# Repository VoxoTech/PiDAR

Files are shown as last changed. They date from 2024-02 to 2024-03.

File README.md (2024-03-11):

# PiDAR - DIY 360° 3D Panorama Scanner
## WORK IN PROGRESS!

### Core Features:
- **LiDAR**: custom serial driver for LDRobot **LD06**, **LD19** or **STL27L**
    - CRC package integrity check
    - calibrated PWM control using curve fitting
    - 2D live visualization and export (numpy or CSV)

- **Panorama**: 6K 360° spherical map
    - stitched from fisheye photos using [**Hugin** Panorama photo stitcher](https://hugin.sourceforge.io/)
    - constant camera exposure by reading EXIF data of automatic
    - constant white balance by iterative optimization of color gains

- **3D Scene**: assembly of 3D scenes from 2D planes based on angle and offsets
    - sampling **vertex colors from panorama**
    - Open3D visualization and export (PCD, PLY or [e57](https://github.com/davidcaron/pye57))
    - aligning multiple scenes using **global registration** and **ICP fine-tuning**
    - **Poisson Surface Meshing** (very slow on Pi4, recommended to run on PC)

### Hardware Specs:

- LDRobot LD06, LD19 or STL27L LiDAR
- Raspberry Pi HQ Camera with ArduCam M12 Lens [(M25156H18, p.7)](https://www.arducam.com/doc/Arducam_M12_Lens_Kit_for_Pi_HQ_Camera.pdf)
- Raspberry Pi 4
- NEMA17 42-23 stepper with A4988 driver

- Power Supply: 
    - v1: 2x _18650_ Batteries (7.2V) with step-down converter
    - v2: 10.000 mAh USB Powerbank with step-up converter

- 3D printed: 
    - custom housing with tripod mount ([v1 here](mechanical_design/v1))
    - M12 to C-Mount lens adapter ([thingiverse.com](https://www.thingiverse.com/thing:4444398))
    - NEMA17 planetary reduction gearbox ([printables.com](https://www.printables.com/de/model/782336-nema17-planetary-gearbox-fixed))

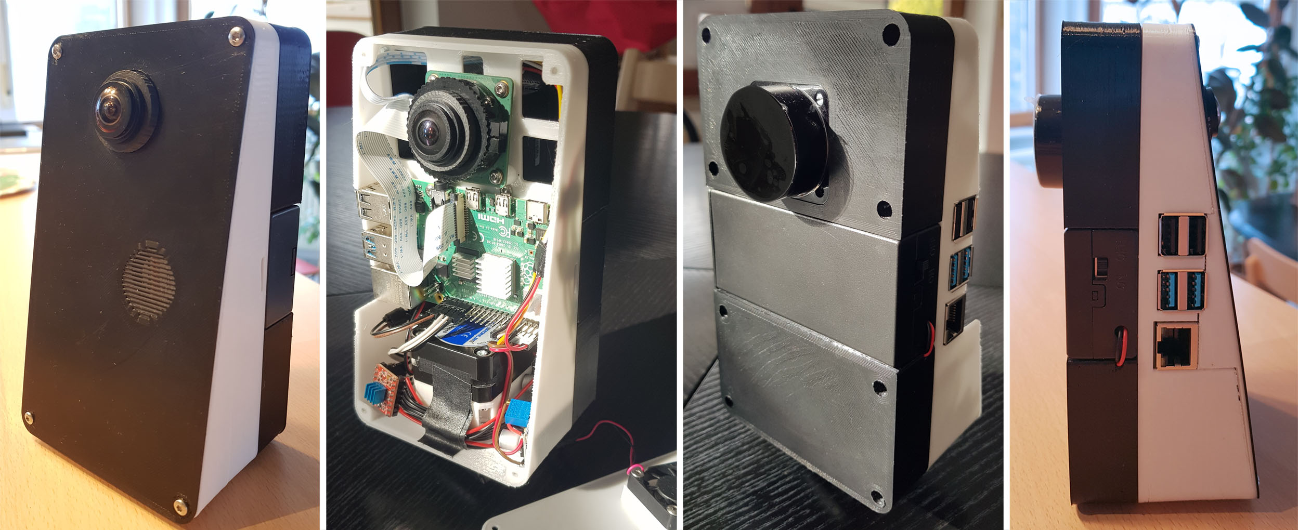
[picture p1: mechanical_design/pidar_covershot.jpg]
PiDAR 360° Laserscanner

Version 1 (using 2x 18650 Batteries):

## wiring

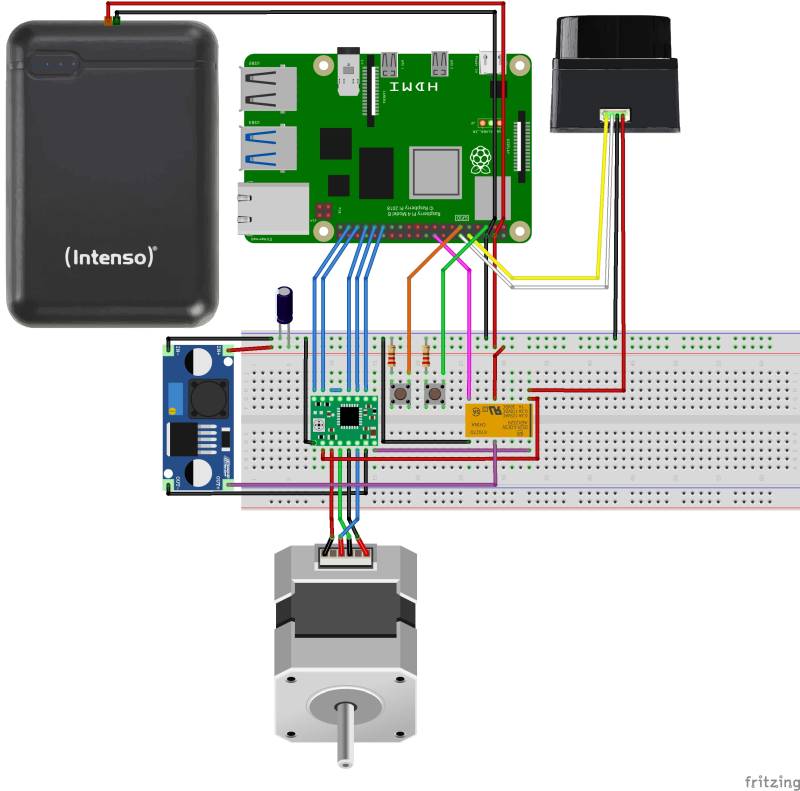
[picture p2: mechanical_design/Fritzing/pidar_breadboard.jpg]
breadboard version 2.0.1


Version 2 - (37Wh Powerbank with Step-Up converter + Relay for power efficiency)

### LD06 / STL27L:
- UART Tx (yellow)
- PWM (white)
- GND (black)
- VCC 5V (red)

### Raspberry Pi:
- LD06 UART0 Rx: GP15
- LD06 PWM0: GP18
- Power Button: GP03
- Scan Button: GP17
- A4988 direction: GP26, step: GP19
- A4988 microstepping mode: GP5, GP6, GP13

### Power Button 
- Wakeup is hardwired to Pin 3
- install [Shutdown script](https://github.com/Howchoo/pi-power-button)

### Power LED and CPU fan
    sudo nano /boot/firmware/config.txt

    # CPU fan at lower temp
    dtoverlay=gpio-fan,gpiopin=4,temp=45000

    # Power LED Heartbeat:
    dtparam=pwr_led_trigger=timer

### Scan Button: register GPIO interrupt

create new service for autostart

    sudo nano /etc/systemd/system/pidar.service

content:

    [Unit]
    Description=GPIO interrupt for PiDAR Scan Button
    After=network.target

    [Service]
    Type=simple
    ExecStart=/usr/bin/python3 /home/pi/Documents/PiDAR/gpio_interrupt.py
    Restart=always
    RestartSec=2

    [Install]
    WantedBy=multi-user.target

reload daemon, enable and start service:

    sudo systemctl daemon-reload
    sudo systemctl enable pidar.service
    sudo systemctl start pidar.service

check service if necessary:

    sudo systemctl status pidar.service

## Serial Protocol
### LD06
baudrate 230400, data bits 8, no parity, 1 stopbit  
sampling frequency 4500 Hz, scan frequency 5-13 Hz, distance 2cm - 12 meter, ambient light 30 kLux

total package size: 48 Byte, big endian.
- starting character：Length 1 Byte, fixed value 0x54, means the beginning of data packet;
- Data Length: Length 1 Byte, the first three digits reserved, the last five digits represent the number of measured points in a packet, currently fixed value 12;
- speed：Length 2 Byte, in degrees per second;
- Start angle: Length: 2 Byte; unit: 0.01 degree;
- Data: Length 36 Byte; containing 12 data points with 3 Byte each: 2 Byte distance (unit: 1 mm), 1 Byte luminance. For white objects within 6m, the typical luminance is around 200.
- End Angle: Length: 2 Byte; unit: 0.01 degree；
- Timestamp: Length 2 Bytes in ms, recount if reaching to MAX 30000；
- CRC check: Length 1 Byte

The Angle value of each data point is obtained by linear interpolation of the starting angle and the ending angle.  
The calculation method of the angle is as following:

    step = (end_angle – start_angle)/(len – 1)  
    angle = start_angle + step*i  

len is the length of the packet, and the i value range is [0, len].

## set Permission for UART on Raspberry Pi
temporary solution: 

    sudo chmod a+rw /dev/ttyS0

### old solution: make it permanent by disabling password for chmod:  

    sudo visudo
    pi ALL=(ALL:ALL) NOPASSWD: /usr/bin/chmod a+rw /dev/ttyS0

then execute the _temporary_ solution from python:

    import subprocess
    command = "sudo chmod a+rw /dev/ttyS0"
    process = subprocess.Popen(command.split(), stdout=subprocess.PIPE)
    output, error = process.communicate()

### new solution: grant permissions to the serial port using udev rules 

(TODO: check and remove old!)
- forget about `visudo` and the subprocess call above.
- Open a terminal and run the following command: `sudo nano /etc/udev/rules.d/50-ttyS0.rules`
- Write the following line in the file and save it: `KERNEL=="ttyS0",GROUP="dialout",MODE="0660"`
- Run the following command to check if your user is a member of the dialout group: `groups`
- If you see `dialout` in the output, you are already a member of the group. If not, run the following command to add your user to the group: `sudo usermod -a -G dialout pi`
- Run the following command to reload the udev rules: `sudo udevadm control --reload-rules`
- Unplug and replug the serial device, or reboot the system, to apply the changes.

## Hardware PWM on Raspberry Pi
enable GPIO_18 (PWM0) and GPIO_19 (PWM1)
    
    echo "dtoverlay=pwm-2chan" >> /boot/config.txt 

check if "pwm_bcm2835" now exists:

    lsmod | grep pwm

Install [RPi Hardware PWM library](https://github.com/Pioreactor/rpi_hardware_pwm):

    pip install rpi-hardware-pwm

## Panorama Stitching
install Hugin with enblend plugin

    sudo apt-get install hugin-tools enblend

## LDRobot LiDAR Specs

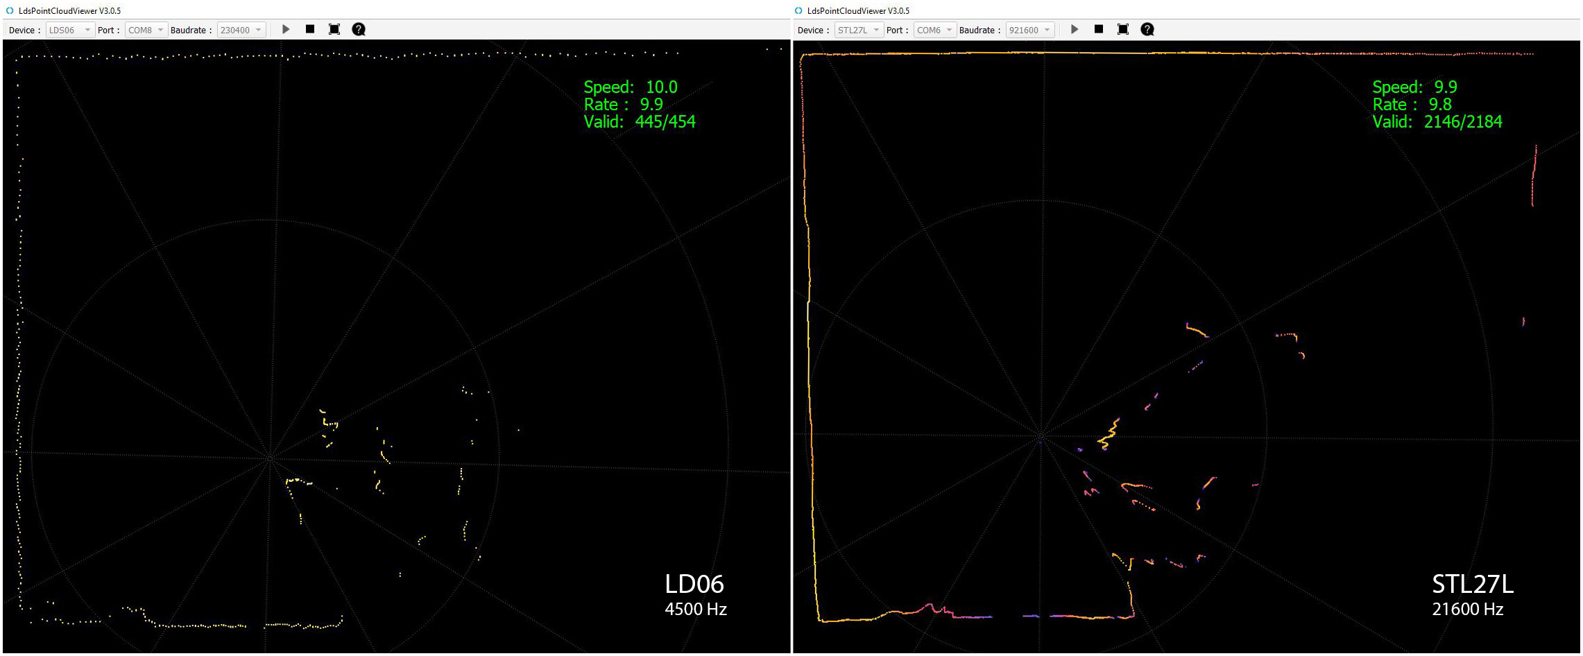
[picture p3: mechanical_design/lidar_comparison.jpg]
LD06 vs. STL27L


LD06: 
- sampling frequency: 4500 Hz
- baudrate 230400
- [Sales page](https://www.inno-maker.com/product/lidar-ld06/)
- [mechanical Datasheet](https://www.inno-maker.com/wp-content/uploads/2020/11/LDROBOT_LD06_Datasheet.pdf)
- [Protocol Description](https://storage.googleapis.com/mauser-public-images/prod_description_document/2021/315/8fcea7f5d479f4f4b71316d80b77ff45_096-6212_a.pdf)

STL27L:
- sampling frequency: 21600 Hz
- baudrate 921600
- [datasheet](https://github.com/May-DFRobot/DFRobot/blob/master/SEN0589_Datasheet.pdf)
- [wiki](https://www.waveshare.com/wiki/DTOF_LIDAR_STL27L)
- ROS2 driver [git](https://github.com/ldrobotSensorTeam/ldlidar_stl_ros2?tab=readme-ov-file#Instructions)

## Troubleshooting

### poor performance of VS Code on Raspberry Pi
disable hardware acceleration for VS Code ([source](https://code.visualstudio.com/docs/setup/raspberry-pi))

    Preferences: Configure Runtime Arguments  
    Set "disable-hardware-acceleration": true

### pye57 on Raspberry Pi
there is no wheel for arm64. build requires libxerces:

    sudo apt install libxerces-c-dev
    pip install pye57

## links and references:

inspirations
- [LIDAR_LD06_python_loder](https://github.com/henjin0/LIDAR_LD06_python_loder) and [Lidar_LD06_for_Arduino](https://github.com/henjin0/Lidar_LD06_for_Arduino) by Inoue Minoru ("[henjin0](https://github.com/henjin0)")
- [ShaunPrice's](https://github.com/ShaunPrice/360-camera) StereoPi-supporting fork of [BrianBock's](https://github.com/BrianBock/360-camera) 360-camera script
- StereoPi Article on [Medium](https://medium.com/stereopi/stitching-360-panorama-with-raspberry-pi-cm3-stereopi-and-two-fisheye-cameras-step-by-step-guide-aeca3ff35871)

another Lidar implementation in Python
- [pyLIDAR](https://github.com/Paradoxdruid/pyLIDAR)

ICP implementations:
- Aeva [Doppler-ICP](https://github.com/aevainc/Doppler-ICP/blob/main/README.md)
- Photogrammetry & Robotics Bonn [KISS-ICP](https://github.com/PRBonn/kiss-icp) and [Lidar-Visualizer](https://github.com/PRBonn/lidar-visualizer)

3D Demo Data for global registration, ICP, meshing etc.:
- [BunnyMesh.ply](https://github.com/isl-org/open3d_downloads/releases/download/20220201-data/BunnyMesh.ply) from [20220201-data](https://github.com/isl-org/open3d_downloads/releases/tag/20220201-data)
- [DemoICPPointClouds.zip](https://github.com/isl-org/open3d_downloads/releases/download/20220301-data/DemoICPPointClouds.zip) from [20220301-data](https://github.com/isl-org/open3d_downloads/releases/tag/20220301-data)

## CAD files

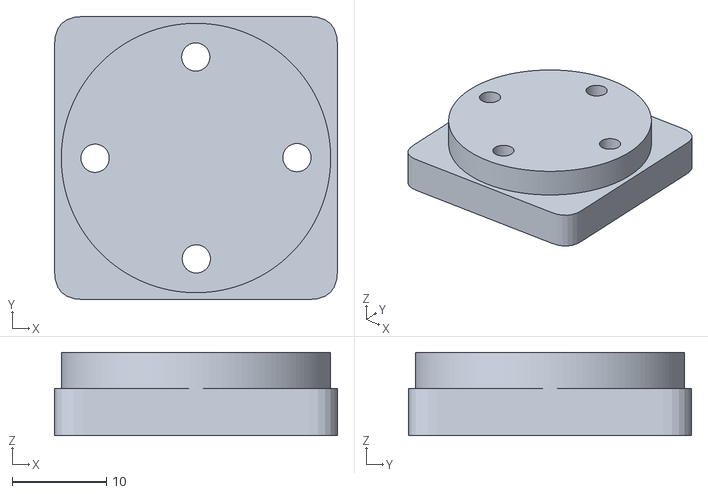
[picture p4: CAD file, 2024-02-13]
mechanical_design/v1/tripod_adapter.obj
30.0 x 30.0 x 8.84

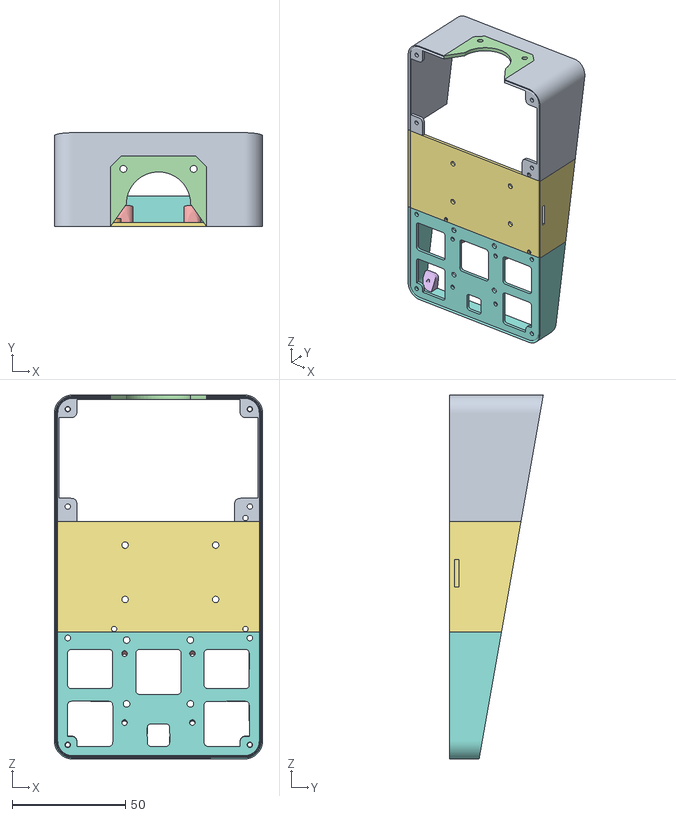
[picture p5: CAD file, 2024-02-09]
mechanical_design/v1/middle.obj
92.0 x 41.3 x 160.8
Frame
Pi_Halterung
gear_lid_unten
kamera_halterung

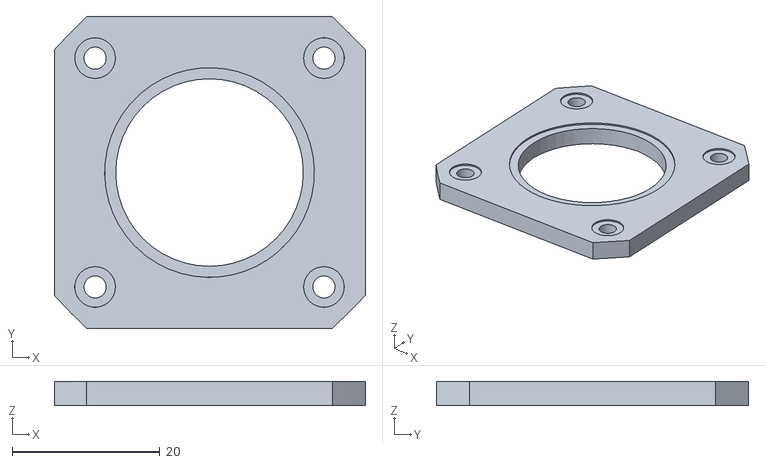
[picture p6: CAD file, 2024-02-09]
mechanical_design/v1/stepper.obj
42.1 x 42.3 x 3.26

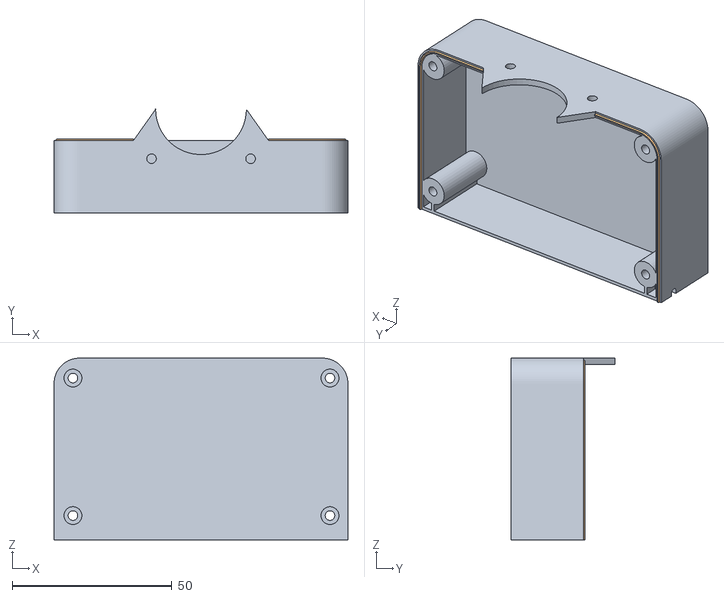
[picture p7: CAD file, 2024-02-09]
mechanical_design/v1/back2.obj
92.0 x 32.4 x 56.9
back_down

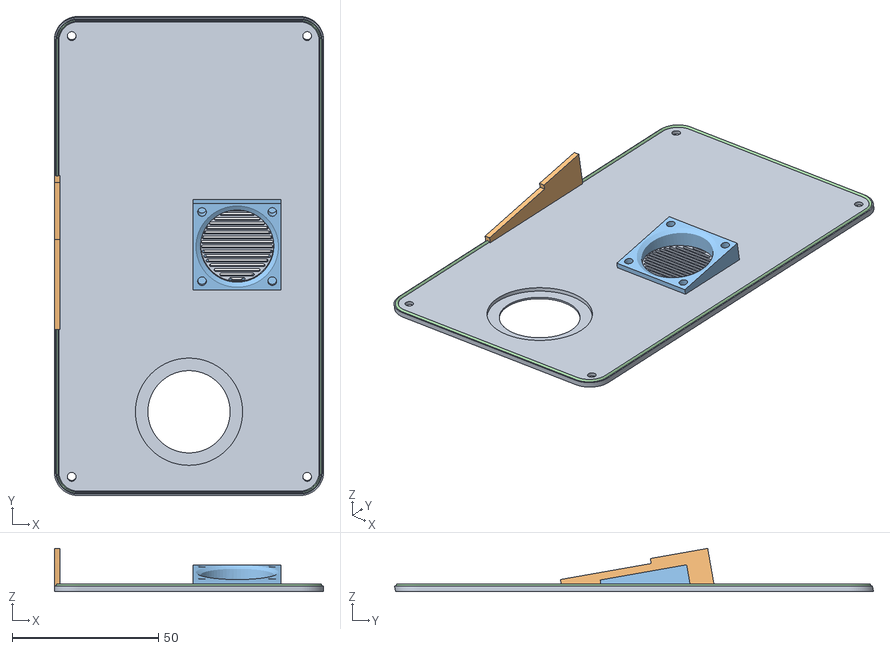
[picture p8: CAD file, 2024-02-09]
mechanical_design/v1/front.obj
92.0 x 163.6 x 14.8
Front

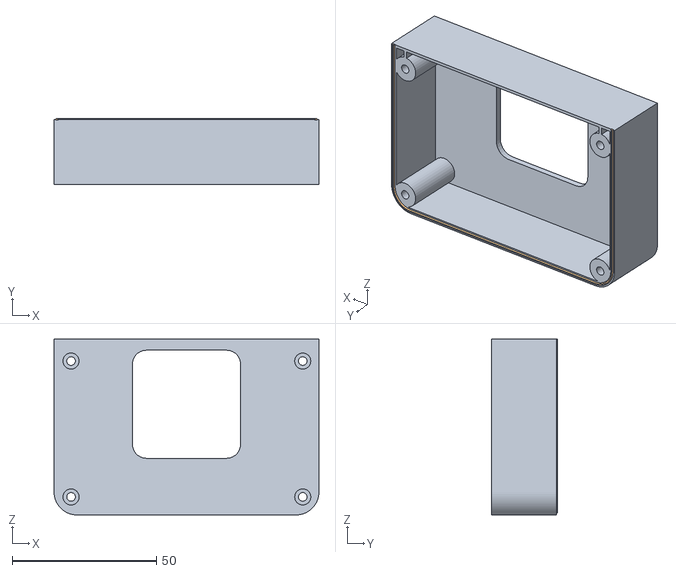
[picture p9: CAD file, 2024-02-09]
mechanical_design/v1/back1.obj
92.0 x 23.1 x 61.1
Back_up

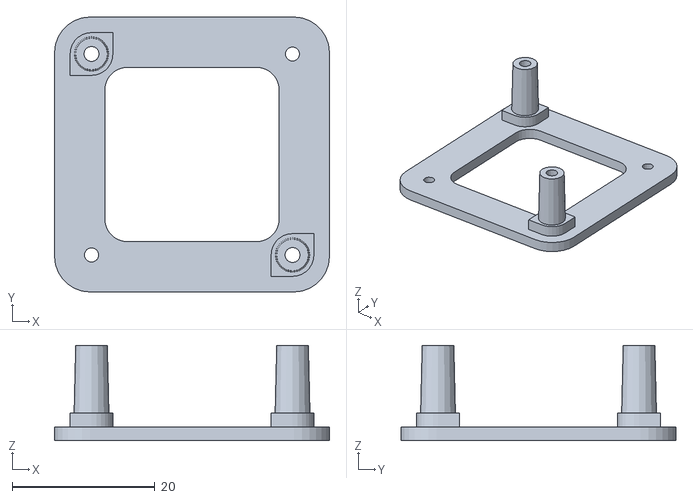
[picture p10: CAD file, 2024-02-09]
mechanical_design/v1/lidar.obj
38.6 x 38.6 x 13.4

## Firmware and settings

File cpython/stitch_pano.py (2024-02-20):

from lib.file_utils import list_files
from lib.pano_utils import hugin_stitch


if __name__ == "__main__":
    # Get all jpg files in the directory
    files = list_files("panocam/images", type="jpg")
    print(len(files), "images found.")

    files = [files[0], files[2], files[4], files[6]]

    hugin_stitch(files, 
                 template="panocam/template_4.pto",
                 width=3600,
                 output_path="export/pano.jpg",
                 tmp_dir="panocam/tmp")

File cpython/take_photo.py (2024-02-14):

"""
https://codefather.tech/blog/shell-command-python/
https://codefather.tech/blog/exit-bash-script/
"""

import subprocess


def take_photo(filename, save_raw=False):

    params = {
        "--immediate":  "",
        "--nopreview":  "",
        "--rotation":   0,  # only 180° step
        "--output":     filename,
        "--quality":    100,
        "--width":      4056,
        "--height":     3040,
        "--gain":       1,
        "--denoise":    "cdn_hq",  # cdn_off, cdn_fast, cdn_hq
        "--awb":        "auto",
        "--shutter":    100000,  # in microseconds
        "--sharpness":  0.5 ,
        "--saturation": 0.7
    }

    if save_raw:
        params["--raw"] = ""
    
    # build command string
    params["--encoding"] = params['--output'].split('.')[-1]
    cmd_string = "rpicam-still " + " ".join(f"{k} {v}" for k, v in params.items())

    # execute command
    retval = subprocess.run(cmd_string, shell=True, capture_output=True, text=True)
    # print(retval)


if __name__ == "__main__":
    from time import time
    import os

    filename = os.path.join("panocam/images", str(time()) + ".jpg")
    take_photo(filename, save_raw=False)

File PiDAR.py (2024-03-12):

import RPi.GPIO as GPIO  # type: ignore
import numpy as np
from time import sleep

from lib.platform_utils import allow_serial
# from lib.matplotlib_2D import plot_2D
from lib.lidar_driver import LD06  #, STL27L
from lib.a4988_driver import A4988
from lib.rpicam_utils import take_photo, estimate_camera_parameters
from lib.pano_utils import hugin_stitch
from lib.file_utils import make_dir


# legacy code: allow access to serial port on Raspberry Pi
allow_serial()

DEBUG = False

# GPIO SETUP
GPIO.setmode(GPIO.BCM)
GPIO.setwarnings(DEBUG)

# ENABLES
enable_camera = True
enable_lidar = True
enable_stitching = True                     # requires enable_camera

# LiDAR DRIVER
PORT = '/dev/ttyS0'                         # {'Windows': 'COM10', 'RaspberryPi': '/dev/ttyS0', 'Linux': '/dev/ttyUSB0'}  # dmesg | grep "tty"
OFFSET = np.pi / 2                          # = 90°
FORMAT = 'npy'                              # 'npy' or 'csv' or None
DATA_DIR = "data/scan_02"
VIS = None                                  # plot_2D() or None
OUT_LEN = 40                                # visualize after every nth batch

# A4988 DRIVER
DIR_PIN = 26
STEP_PIN = 19
MS_PINS = [5, 6, 13]
MICROSTEPS = 16                             # microstepping mode
MS_TABLE = {16: 11885, 8: 5942, 4: 2971}    # table of microsteps per revolution
MS360 = MS_TABLE[MICROSTEPS]                # microsteps per revolution
TARGET_RES = 0.5                            # desired resolution in degrees
STEP_DELAY = 0.0005                         # seconds between steps
GEAR_RATIO = 1 + 38/14                      # planetary gear reduction ratio
STEP_ANGLE = 1.8                            # degrees per full step (360 / 200)

SPEED = 4500 * TARGET_RES / 360             # 6.25 Hz for 0.5° resolution

steps = int(MS360 * TARGET_RES / 360)       # 16
h_res = 360 * steps / MS360                 # 0.48464451
scan_delay = 1 / (4500 * TARGET_RES / 360)  # 0.16

# Power Relay
RELAY_PIN = 24
GPIO.setup(RELAY_PIN, GPIO.OUT)
GPIO.output(RELAY_PIN, 1)                   # Relay Power on

# photos
IMGCOUNT = 4
raw = False
imglist = []
template_path = f"panocam/template_{IMGCOUNT}.pto"
PANO_WIDTH = 3600
set_gain = 1
awb_thres=0.01

hsteps = 180 / h_res
packages_per_revolution =  58  # round(4500 / 12 / 6.43)
max_packages = hsteps * packages_per_revolution


# calibrate camera
if enable_camera:
    # extract exposure time and gain from exif data, iterate through Red/Blue Gains for custom AWB
    exposure_time, gain, awbgains = estimate_camera_parameters(set_gain=set_gain, awb_thres=awb_thres)
    if DEBUG:
        print("[RESULT] AE:", exposure_time, "| Gain:", gain, "| AWB R:", round(awbgains[0],3), "B:", round(awbgains[1],3))

# ensure output directory
make_dir(DATA_DIR)

# initialize stepper
stepper = A4988(DIR_PIN, 
                STEP_PIN, 
                MS_PINS, 
                delay=STEP_DELAY, 
                step_angle=STEP_ANGLE, 
                microsteps=MICROSTEPS, 
                gear_ratio=GEAR_RATIO)

# initialize lidar
if enable_lidar:
    lidar = LD06(port=PORT, 
                 speed=SPEED, 
                 visualization=VIS, 
                 offset=OFFSET,
                 format=FORMAT, 
                 data_dir=DATA_DIR, 
                 out_len=OUT_LEN, 
                 platform='RaspberryPi')
    
    # callback function for lidar.read_loop()
    def move_steps_callback():
        stepper.move_steps(steps)
        lidar.z_angle = stepper.get_current_angle()

    if not enable_camera:
        # wait for lidar to lock rotational speed
        sleep(2)


# MAIN
try:
    # 360° SHOOTING PHOTOS
    if enable_camera:
        for i in range(IMGCOUNT):
            # take HighRes image using fixed values
            imgpath = f"images/image_{round(stepper.get_current_angle(), 2)}.jpg"
            take_photo(path=imgpath, exposure_time=exposure_time, gain=gain, awbgains=awbgains, denoise="cdn_hq", save_raw=raw, blocking=True)
            imglist.append(imgpath)

            stepper.move_angle(360/IMGCOUNT)

    # 180° SCAN
    if enable_lidar:
        lidar.read_loop(callback=move_steps_callback, max_packages=max_packages)  #  TODO: hsteps?
        stepper.move_to_angle(0)   # return to 0°
    

    # STITCHING PROCESS (NON-BLOCKING)
    if enable_stitching and enable_camera:
        project_path = hugin_stitch(imglist, template=template_path, width=PANO_WIDTH)


finally:
    print("PiDAR STOPPED")
    if enable_lidar:
        lidar.close()
    stepper.close()

    # Relay Power off
    GPIO.output(RELAY_PIN, 0)
    GPIO.cleanup(RELAY_PIN)

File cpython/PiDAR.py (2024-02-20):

import numpy as np
import RPi.GPIO as GPIO  # type: ignore
from time import sleep

from lib.platform_utils import allow_serial
from lib.matplotlib_2D import plot_2D
from lib.lidar_driver import LD06  #, STL27L
from lib.a4988_driver import A4988
from lib.file_utils import save_data, make_dir


# allow access to serial port on Raspberry Pi
allow_serial()

# CONSTANTS
PORT = '/dev/ttyS0'         # {'Windows': 'COM10', 'RaspberryPi': '/dev/ttyS0', 'Linux': '/dev/ttyUSB0'}  # dmesg | grep "tty"
PWM_DC = 0.1                # duty cycle: 0.23 = 10 Hz, 0.1 = 4 Hz
OFFSET = np.pi / 2          # = 90°
FORMAT = 'npy'              # 'npy' or 'csv' or None
DTYPE = np.float64          # np.float32
DATA_DIR = "data"
VIS = plot_2D()             # plot_2D() or None
OUT_LEN = 40                # visualize after every nth batch

DIR_PIN = 26                # direction pin
STEP_PIN = 19               # step pin
MS_PINS = [5, 6, 13]        # microstepping mode pins

STEP_DELAY = 0.001         # seconds between steps
STEP_ANGLE = 1.8            # degrees per full step
MICROSTEPS = 16             # microsteps per full step
GEAR_RATIO = 3.7142857      # planetary gear reduction ratio

HORIZONTAL_ANGLE = 0.4846444  # degrees
HORIZONTAL_STEPS = 16


GPIO.setwarnings(False)  # Disable warnings
GPIO.setmode(GPIO.BCM)

GPIO.setup(4, GPIO.IN, pull_up_down=GPIO.PUD_UP)

GPIO.setup(24, GPIO.OUT)
GPIO.output(24, 0)


# ensure output directory
make_dir(DATA_DIR)


lidar   = LD06(port=PORT, pwm_dc = PWM_DC, visualization=VIS, offset=OFFSET,format=FORMAT, dtype=DTYPE, data_dir=DATA_DIR, out_len=OUT_LEN)
stepper = A4988(DIR_PIN, STEP_PIN, MS_PINS, delay=STEP_DELAY, step_angle=STEP_ANGLE, microsteps=MICROSTEPS, gear_ratio=GEAR_RATIO)


## calculate exact amount of steps for the desired angle
#steps = stepper.move_angle(HORIZONTAL_ANGLE)
#print(f"[INFO] {HORIZONTAL_ANGLE}° -> {steps} steps.")




try:
    while True:
        # SCAN-Button pressed
        if not GPIO.input(4):
            # Relay Power on
            GPIO.output(24, 1)

            for z_angle in np.arange(0, 360, HORIZONTAL_ANGLE):
                if lidar.serial_connection.is_open:
                    # lidar.read_loop()  
                
                    if lidar.out_i == lidar.out_len:
                        # print("speed:", round(lidar.speed, 2))
                        
                        # SAVE DATA
                        if lidar.format is not None:
                            save_data(lidar.data_dir, lidar.points_2d, lidar.format)

                        # VISUALIZE
                        if lidar.visualization is not None:
                            lidar.visualization.update_coordinates(lidar.points_2d)
                        lidar.out_i = 0

                    lidar.read()
                    lidar.out_i += 1

                    stepper.move_steps(HORIZONTAL_STEPS)

        else:
            # GPIO.output(24, 0)  # Relay Power of
            sleep(0.1)

finally:
    print("SCANNING STOPPED")
    GPIO.output(24, 0)
    GPIO.cleanup()

    lidar.close()
    stepper.close()

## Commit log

2024-01-04 asyncio and threading
2024-01-06 IMU and other
2024-01-11 restructuring, PiDAR_v2 still broken
    [PiDAR.py, visualize_3D.py]
2024-01-15 cpython fixed, circuitpython still WIP
    [PiDAR.py, a4988_driver.py]
2024-01-16 started unifying python and circuitpython
2024-01-17 use software rendering on raspberry pi
2024-01-21 pico transfer speed measure
2024-01-22 PWM and UART for Raspberry Pi started
2024-01-22 UART and PWM on Raspberry Pi
2024-02-09 circuitpython removed from project
    [back1.obj, back2.obj, front.obj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]
2024-02-13 tripod adapter added
    [tripod_adapter.obj]
2024-02-14 name conflict "platform" resolved"
    [PiDAR.py, visualize_3D.py]
2024-02-15 integrating stepper into main loop
2024-02-20 Relay and Button
2024-02-20 a4988 stepper
2024-02-21 interrupt fixed
2024-02-21 fritzing updated
    [PiDAR_2.0.1.fzz]
2024-02-21 docs updated
    [PiDAR_2.0.1.fzz]
2024-02-24 M12 lens added to BOM
2024-02-28 pointcloud and camera improvements
2024-02-28 boost converter behind single channel relay
    [PiDAR_2.0.1.fzz, PiDAR_2.0.2.fzz]
2024-02-29 trying to fix main loop
    [PiDAR.py]
2024-03-08 visualisation and other minor fixes
    [PiDAR.py]
2024-03-11 CRC check, PID speed
2024-03-11 PID tuning
2024-03-11 curve fitting instead of PID
2024-03-12 stepper driver fixed
2024-03-12 gear ratio calculated
2024-03-12 stepper fix

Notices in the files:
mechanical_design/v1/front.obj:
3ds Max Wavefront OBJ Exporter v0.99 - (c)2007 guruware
